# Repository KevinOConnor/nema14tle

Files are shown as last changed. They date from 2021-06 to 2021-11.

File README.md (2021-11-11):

This is an experimental pcb design for a TLE5012B angle sensor mounted
on the back of a NEMA14 stepper motor.

This is an experiment. There is no support for this project.

The original design of the board is from Voron user "JNP".

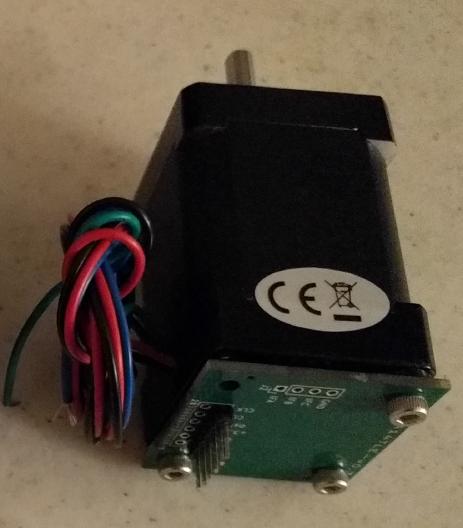
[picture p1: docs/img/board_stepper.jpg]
board_stepper


The PCB design files can be found in the [pcb/](pcb/) directory.  The
boards were designed using [KiCad](https://kicad.org/) and
manufactured using [JLC PCB](https://jlcpcb.com/).

There is some information on the magnet mounting procedure in the
[magnet document](docs/magnet.md).

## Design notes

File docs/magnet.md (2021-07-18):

This document provides information on the procedure used to mount the
pcb and magnet to a nema14 stepper motor.

The tle5012b angle sensor chip requires a diametric magnet to be
attached to the rear stepper motor shaft.  "D42DIA" magnets were
purchased from [K&J Magnetics](https://www.kjmagnetics.com/).

To assist in mounting the magnet, a
[magnet jig](../prints/magnet_jig.stl) was printed.  The jig was
designed for a "Stepper Online 14HS20-1504S" nema14 stepper motor.

The magnet was attached to the stepper motor using super glue
(cyanoacrylate).  The magnet was placed in the jig, a small amount of
super glue was placed on the magnet, and then the jig and magnet were
inserted into the rear of the stepper motor so that the magnet was
pressed against the rear shaft.  If repeating this procedure, be sure
to remove all metal objects from the work area prior to starting.

In order to get proper spacing between the stepper and nema14tle
board, [stepper spacer](../prints/stepper_spacer.stl) parts were
printed.  Three of the four rear screws on the stepper were then
replaced with 50mm M3 screws.  The spacers help position the tle5012b
chip a small distance away from the magnet.  If repeating this
procedure, be sure to leave 1 screw in the stepper motor at all times,
as opening the stepper case may permanently damage the stepper motor.

TODO:

* The magnet jig did not work well, because the magnet had a tendency
  to prematurely pull towards the stepper case and/or shaft.  If doing
  again, I would try to build a magnet jig with space for another
  magnet on the rear of the jig that could hold the primary magnet in
  place until it is firmly attached to the shaft.

* It may be preferable to place a small nylon spacer between magnet
  and stepper motor shaft before gluing.  (So as to reduce magnet
  losses from the magnet through the shaft.)

* This experimental pcb requires several wires to be routed between
  stepper and micro-controller.  Building and routing the resulting
  wire harness was cumbersome.  If doing again, I would try to build a
  pcb with a micro-controller on it to simplify wiring.

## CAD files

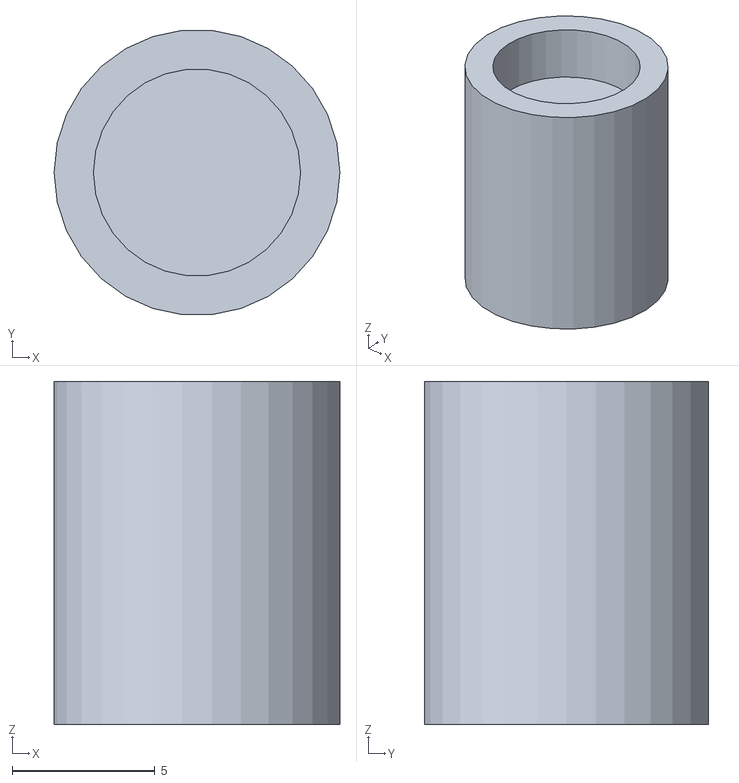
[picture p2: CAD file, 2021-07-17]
prints/magnet_jig.stl
10.0 x 9.95 x 12.0

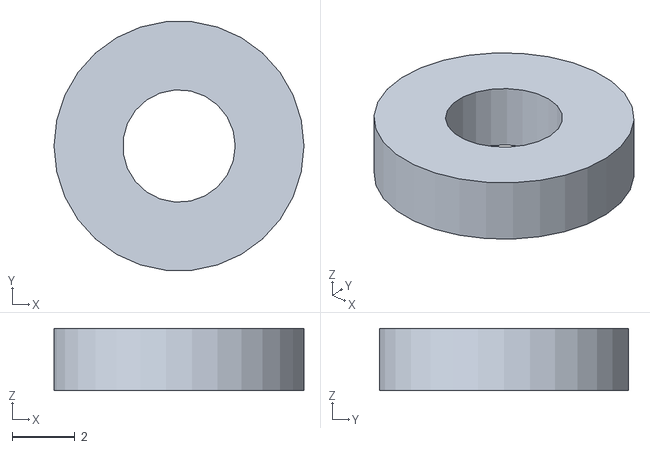
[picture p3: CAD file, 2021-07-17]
prints/stepper_spacer.stl
8.00 x 7.96 x 2.00

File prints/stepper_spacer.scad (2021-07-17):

// Simple stepper motor screw spacers for nema14tle board
//
// Copyright (C) 2021  Kevin O'Connor <kevin@koconnor.net>
//
// This file may be distributed under the terms of the GNU GPLv3 license.

screw_dia = 3.6;
spacer_dia = 8;
CUT = 0.01;
$fs = 0.5;

module stepper_spacer(height) {
    difference() {
        cylinder(d=spacer_dia, h=height);
        translate([0, 0, -CUT])
        cylinder(d=screw_dia, h=height + 2*CUT);
    }
}

//
// Object selection
//

stepper_spacer(2);

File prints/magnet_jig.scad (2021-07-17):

// Holder for magnet to help attach to stepper motor
//
// Copyright (C) 2021  Kevin O'Connor <kevin@koconnor.net>
//
// This file may be distributed under the terms of the GNU GPLv3 license.

magnet_dia = 25.4 / 4 + .9;
magnet_height = 25.4 / 8;
opening_dia = 10;
holder_height = 12;
holder_offset = .5;
$fs = 0.5;

module magnet_holder() {
    difference() {
        cylinder(d=opening_dia, h=holder_height);
        translate([0, 0, holder_height - magnet_height + holder_offset])
        cylinder(d=magnet_dia, h=magnet_height);
    }
}

//
// Object selection
//

magnet_holder();

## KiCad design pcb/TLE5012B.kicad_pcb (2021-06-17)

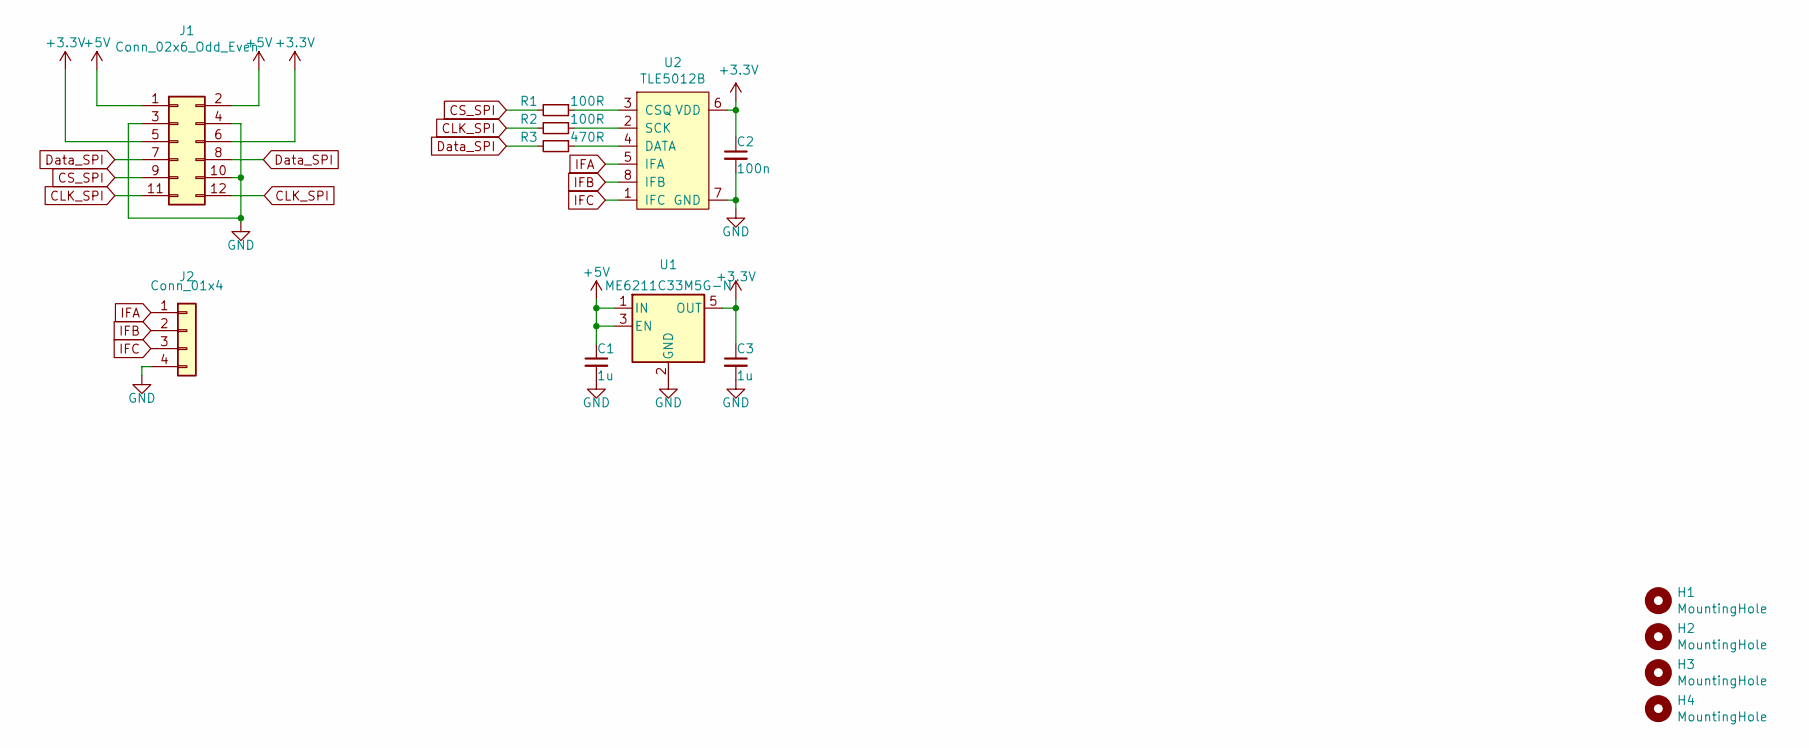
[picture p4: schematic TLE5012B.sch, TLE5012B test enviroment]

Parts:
C1, C3: 1u; C_0603_1608Metric; MFG# 0603B105K250NT; LCSC# C59302
C2: 100n; C_0603_1608Metric; LCSC# C14663
H1, H2, H3, H4: MountingHole; MountingHole_3.2mm_M3
J1: Conn_02x6_Odd_Even; PinHeader_2x06_P2.54mm_Vertical
J2: Conn_01x4; PinHeader_1x04_P2.54mm_Vertical
R1, R2: 100R; R_0603_1608Metric; MFG# MR06X1000FTL; LCSC# C327825
R3: 470R; R_0603_1608Metric; MFG# RS-03K4700FT; LCSC# C116694
U1: ME6211C33M5G-N; SOT-23-5; MFG# ME6211C33M5G-N; LCSC# C82942
U2: TLE5012B; Infineon_PG-DSO-8; LCSC# C123083

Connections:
+3V3: C2.1, C3.1, J1.5, J1.6, U1.5 (OUT), U2.6 (VDD)
+5V: C1.1, J1.1, J1.2, U1.1 (IN), U1.3 (EN)
CLK_SPI: J1.11, J1.12, R2.2
CS_SPI: J1.9, R1.2
Data_SPI: J1.7, J1.8, R3.2
GND: C1.2, C2.2, C3.2, J1.3, J1.4, J1.10, J2.4, U1.2 (GND), U2.7 (GND)
IFA: J2.1, U2.5 (IFA)
IFB: J2.2, U2.8 (IFB)
IFC: J2.3, U2.1 (IFC)
unnamed: R1.1, U2.3 (CSQ)
unnamed: R2.1, U2.2 (SCK)
unnamed: R3.1, U2.4 (DATA)

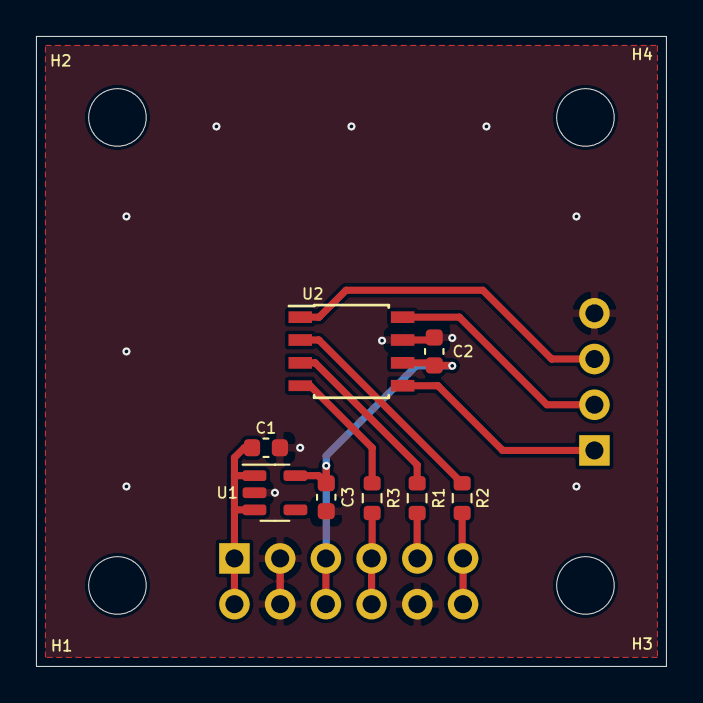
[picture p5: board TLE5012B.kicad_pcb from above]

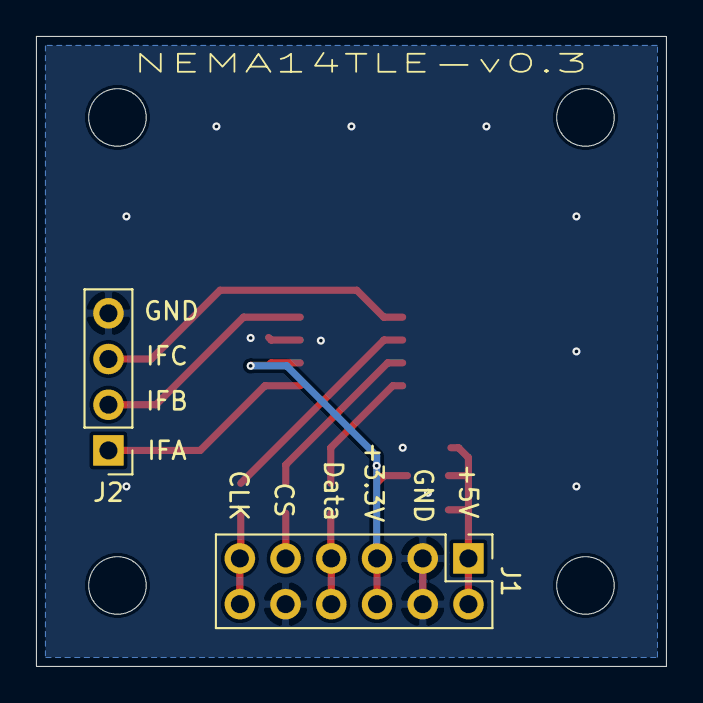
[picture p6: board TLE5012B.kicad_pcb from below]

Board: 2 copper layers, 35.0 x 35.0 mm, 14 parts (2 on the bottom side), 12 nets.

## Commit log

2021-06-17 Initial commit of board design by JNP.
    [TLE5012B.kicad_pcb, TLE5012B.sch]
2021-06-17 pcb: Minor updates to pcb
    Only have one CS pin header (ground the others).
    Add additional ground vias around perimeter of board.
    Update 100nF LCSC part number
    [TLE5012B.kicad_pcb, TLE5012B.sch]
2021-07-17 prints: Add model for 3d-printed stepper motor spacers
    [stepper_spacer.scad, stepper_spacer.stl]
2021-07-17 prints: Add 3d-printer model for magnet attachment tool
    [magnet_jig.scad, magnet_jig.stl]
2021-07-18 docs: Add picture of assembled motor and pcb
2021-07-18 docs: Add information on mounting of board and magnet
2021-07-18 docs: Add note about wiring complexity of current design
2021-11-11 Update README.md
    https://forum.kicad.info/t/warning-avoid-all-links-to-kicad-pcb-org-use-kicad-org/31521/
